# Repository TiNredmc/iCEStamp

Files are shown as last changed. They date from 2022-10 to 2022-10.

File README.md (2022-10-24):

# iCEStamp

iCEStamp. Tiny FPGA core module based on iCE40LP1K-CM36 (iCEStamp1K) and iCE40UL1K-CM36 (iCEStampUL1K). Inspired by postage stamp, with the physical size of just 17.78 * 17.78 * 3.50 mm!

Specification
=

## iCEStamp1k
- FPGA : iCE40LP1K CM36
    - Logic Cells : 1280 cells
    - Block RAM : RAM4K * 16 (64kBits  or 8kBytes)
    - 25 I/O pins
    - Sadly no DSP block and PLL Block
    - Requires external clock/oscillator
    - x1 SPI Hardened IP
- IO Supply voltage : 2v5 to 3v3
- On board 1v2 regulator for core voltage

## iCEStampUL1K
- FPGA : iCE40UL1K CM36
    - Logic Cells : 1248 cells
    - Block RAM : RAM4K * 14 (56kBits or 7kBytes)
    - 26 I/O pins included High current sink for IR and RGB led
    - Internal 48Mhz HF oscillator and 10kHz LF oscillator
    - PLL block included 
    - x2 I2C Hardened IP
    - x1 IR TX/RX Hardened IP
    - x1 RGB PWM Hardened IP
- IO Supply voltage : 2v5 to 3v3
- On board 1v2 regulator for core voltage

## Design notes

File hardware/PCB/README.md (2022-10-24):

# Schematics and PCBs for iCEStamp1K and iCEStampUL1K module

Both of them are 4 layers board. Manufactured by OSHpark with the minimum trace width = 3.5 mil

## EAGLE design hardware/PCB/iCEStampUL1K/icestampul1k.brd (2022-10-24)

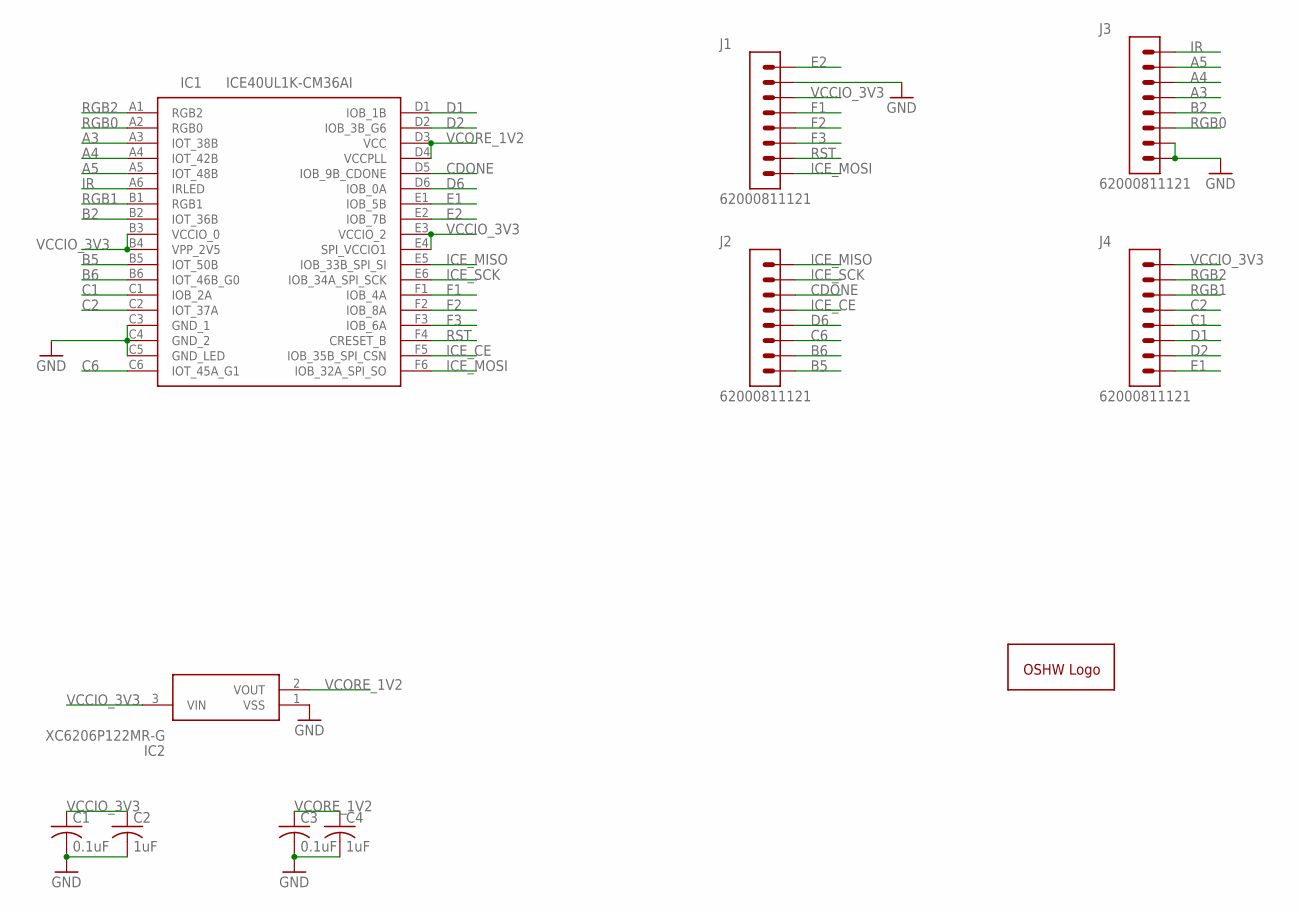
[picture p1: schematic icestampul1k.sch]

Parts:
C1, C3: 0.1uF; C0603
C2, C4: 1uF; C0603
GOLD_ORB_SM1: OSHWLOGOLOGO5MM; OSHW_5MM
IC1: ICE40UL1K-CM36AI; BGA36C40P6X6_250X250X91
IC2: XC6206P122MR-G; SOT95P280X130-3N
J1, J2, J3, J4: 62000811121

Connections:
A3: IC1.A3 (IOT_38B), J3.4
A4: IC1.A4 (IOT_42B), J3.3
A5: IC1.A5 (IOT_48B), J3.2
B2: IC1.B2 (IOT_36B), J3.5
B5: IC1.B5 (IOT_50B), J2.8
B6: IC1.B6 (IOT_46B_G0), J2.7
C1: IC1.C1 (IOB_2A), J4.5
C2: IC1.C2 (IOT_37A), J4.4
C6: IC1.C6 (IOT_45A_G1), J2.6
CDONE: IC1.D5 (IOB_9B_CDONE), J2.3
D1: IC1.D1 (IOB_1B), J4.6
D2: IC1.D2 (IOB_3B_G6), J4.7
D6: IC1.D6 (IOB_0A), J2.5
E1: IC1.E1 (IOB_5B), J4.8
E2: IC1.E2 (IOB_7B), J1.1
F1: IC1.F1 (IOB_4A), J1.4
F2: IC1.F2 (IOB_8A), J1.5
F3: IC1.F3 (IOB_6A), J1.6
GND: C1.2, C2.2, C3.2, C4.2, IC1.C3 (GND_1), IC1.C4 (GND_2), IC1.C5 (GND_LED), IC2.1 (VSS), J1.2, J3.7, J3.8
ICE_CE: IC1.F5 (IOB_35B_SPI_CSN), J2.4
ICE_MISO: IC1.E5 (IOB_33B_SPI_SI), J2.1
ICE_MOSI: IC1.F6 (IOB_32A_SPI_SO), J1.8
ICE_SCK: IC1.E6 (IOB_34A_SPI_SCK), J2.2
IR: IC1.A6 (IRLED), J3.1
RGB0: IC1.A2 (RGB0), J3.6
RGB1: IC1.B1 (RGB1), J4.3
RGB2: IC1.A1 (RGB2), J4.2
RST: IC1.F4 (CRESET_B), J1.7
VCCIO_3V3: C1.1, C2.1, IC1.B3 (VCCIO_0), IC1.B4 (VPP_2V5), IC1.E3 (VCCIO_2), IC1.E4 (SPI_VCCIO1), IC2.3 (VIN), J1.3, J4.1
VCORE_1V2: C3.1, C4.1, IC1.D3 (VCC), IC1.D4 (VCCPLL), IC2.2 (VOUT)

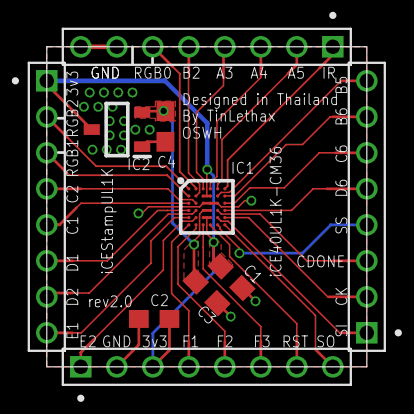
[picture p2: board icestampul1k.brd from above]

Board: 4 copper layers, 17.8 x 17.8 mm, 11 parts (1 on the bottom side), 30 nets.

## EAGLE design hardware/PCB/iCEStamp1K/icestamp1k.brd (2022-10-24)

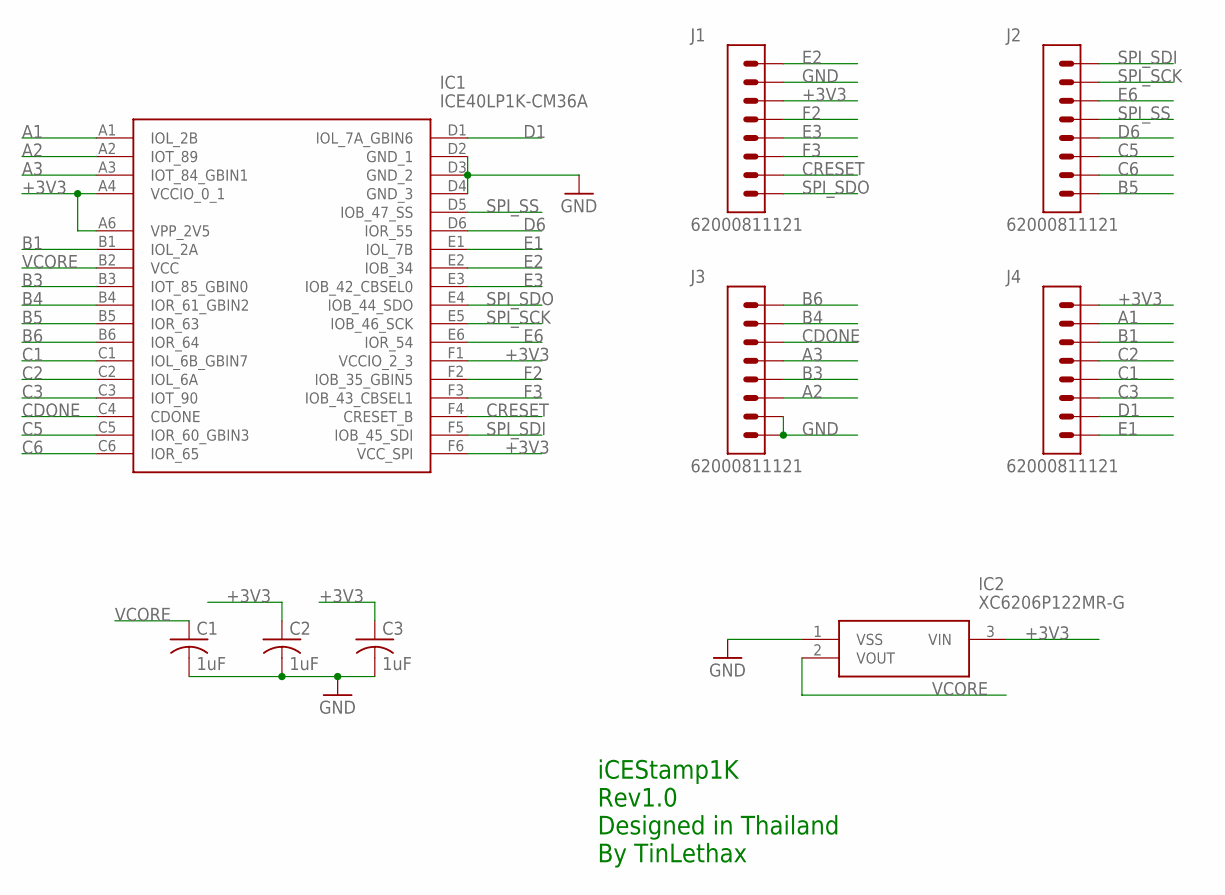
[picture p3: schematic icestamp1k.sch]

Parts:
C1, C2, C3: 1uF; C0603
IC1: ICE40LP1K-CM36A; BGA36C40P6X6_250X250X100
IC2: XC6206P122MR-G; SOT95P280X130-3N
J1, J2, J3, J4: 62000811121

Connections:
+3V3: C2.1, C3.1, IC1.A4 (VCCIO_0_1), IC1.A6 (VPP_2V5), IC1.F1 (VCCIO_2_3), IC1.F6 (VCC_SPI), IC2.3 (VIN), J1.3, J4.1
A1: IC1.A1 (IOL_2B), J4.2
A2: IC1.A2 (IOT_89), J3.6
A3: IC1.A3 (IOT_84_GBIN1), J3.4
B1: IC1.B1 (IOL_2A), J4.3
B3: IC1.B3 (IOT_85_GBIN0), J3.5
B4: IC1.B4 (IOR_61_GBIN2), J3.2
B5: IC1.B5 (IOR_63), J2.8
B6: IC1.B6 (IOR_64), J3.1
C1: IC1.C1 (IOL_6B_GBIN7), J4.5
C2: IC1.C2 (IOL_6A), J4.4
C3: IC1.C3 (IOT_90), J4.6
C5: IC1.C5 (IOR_60_GBIN3), J2.6
C6: IC1.C6 (IOR_65), J2.7
CDONE: IC1.C4 (CDONE), J3.3
CRESET: IC1.F4 (CRESET_B), J1.7
D1: IC1.D1 (IOL_7A_GBIN6), J4.7
D6: IC1.D6 (IOR_55), J2.5
E1: IC1.E1 (IOL_7B), J4.8
E2: IC1.E2 (IOB_34), J1.1
E3: IC1.E3 (IOB_42_CBSEL0), J1.5
E6: IC1.E6 (IOR_54), J2.3
F2: IC1.F2 (IOB_35_GBIN5), J1.4
F3: IC1.F3 (IOB_43_CBSEL1), J1.6
GND: C1.2, C2.2, C3.2, IC1.D2 (GND_1), IC1.D3 (GND_2), IC1.D4 (GND_3), IC2.1 (VSS), J1.2, J3.7, J3.8
SPI_SCK: IC1.E5 (IOB_46_SCK), J2.2
SPI_SDI: IC1.F5 (IOB_45_SDI), J2.1
SPI_SDO: IC1.E4 (IOB_44_SDO), J1.8
SPI_SS: IC1.D5 (IOB_47_SS), J2.4
VCORE: C1.1, IC1.B2 (VCC), IC2.2 (VOUT)

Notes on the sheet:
iCEStamp1K Rev1.0
Designed in Thailand By TinLethax

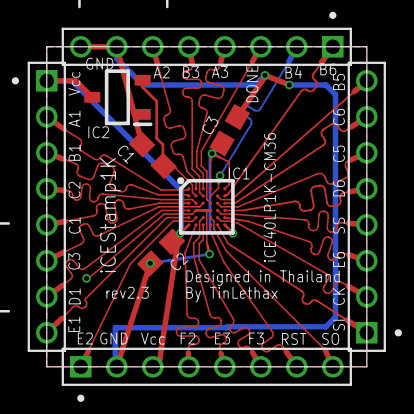
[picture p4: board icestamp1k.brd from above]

Board: 4 copper layers, 17.8 x 17.8 mm, 9 parts (0 on the bottom side), 30 nets.

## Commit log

2022-10-24 Added iCEStamp1K and iCEStampUL1K Schematics and PCBs.
    [icestamp1k.brd, icestamp1k.sch, icestampul1k.brd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]
2022-10-24 Added README of PCB.
2022-10-24 Added EAGLE CAD Library for both iCEStamp1K and iCEStampUL1K modules.
